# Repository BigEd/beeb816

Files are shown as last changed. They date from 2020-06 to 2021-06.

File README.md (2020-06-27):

# beeb816
65816 upgrade for BBC Micro, including lots of fast RAM

rtl           -       original level1b RTL
emu6502_rtl   -       stripped back 6502 emulation only, trialling clock delays for CPU vs BBC
trial_rtl     -       extension of above to allow access to high memory in 816 mode only
trial2_rtl    -       extension of above to allow ROM/RAM remapping, but no clock switching
trial3_rtl    -       full functionality with synchronous CPU clock/async BBC clock switch
trial4_rtl    -       full functionality with async CPU and BBC clock switches
trial5_rtl    -       full functionality with async CPU and BBC clock switches, force all mapping/selection to occur in PHI1/switch in PHI1
trial6_rtl    -       full functionality with synchronous CPU clock/async BBC clock switch, force all mapping/selection to occur in PHI1/switch in PHI1

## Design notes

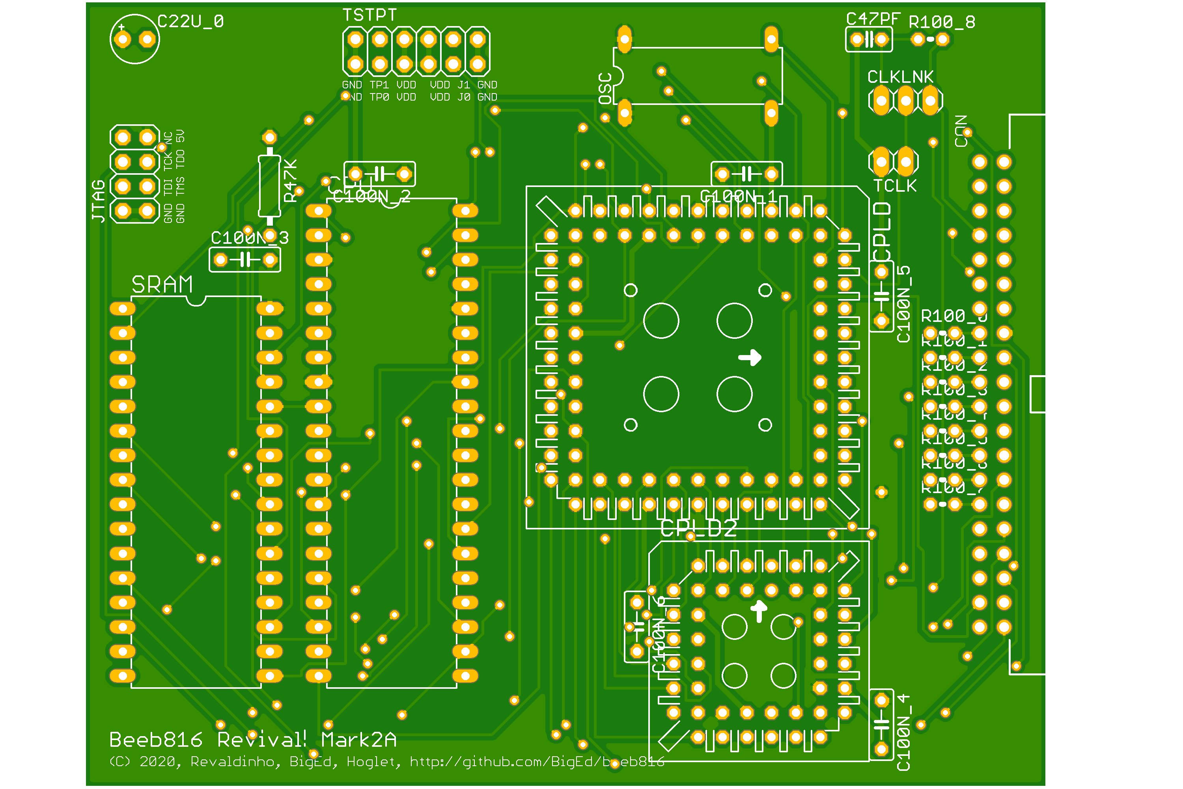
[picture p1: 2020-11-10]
doc/l1b_mk2a_top.png

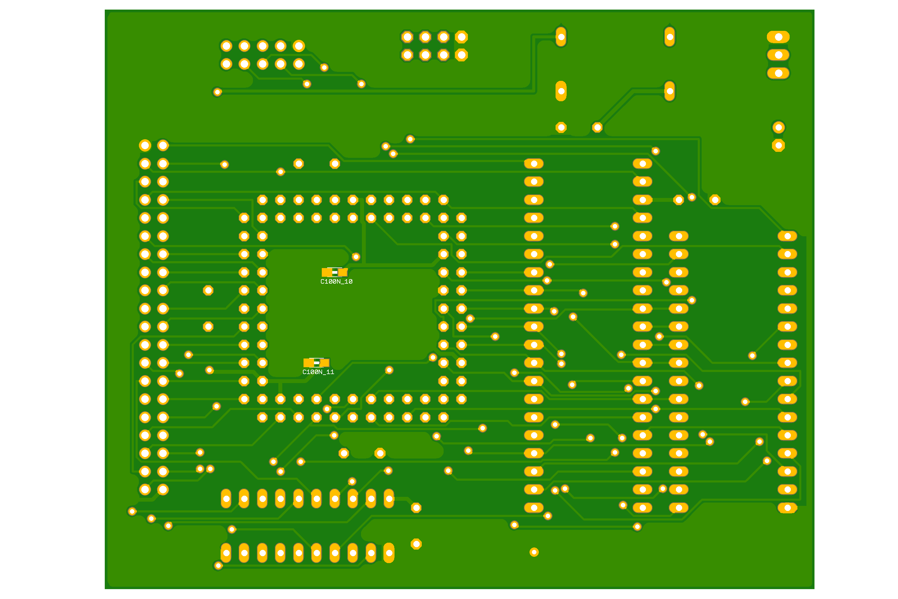
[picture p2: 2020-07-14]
pcb/releases/rc-1/l1b_mk2_bot.png

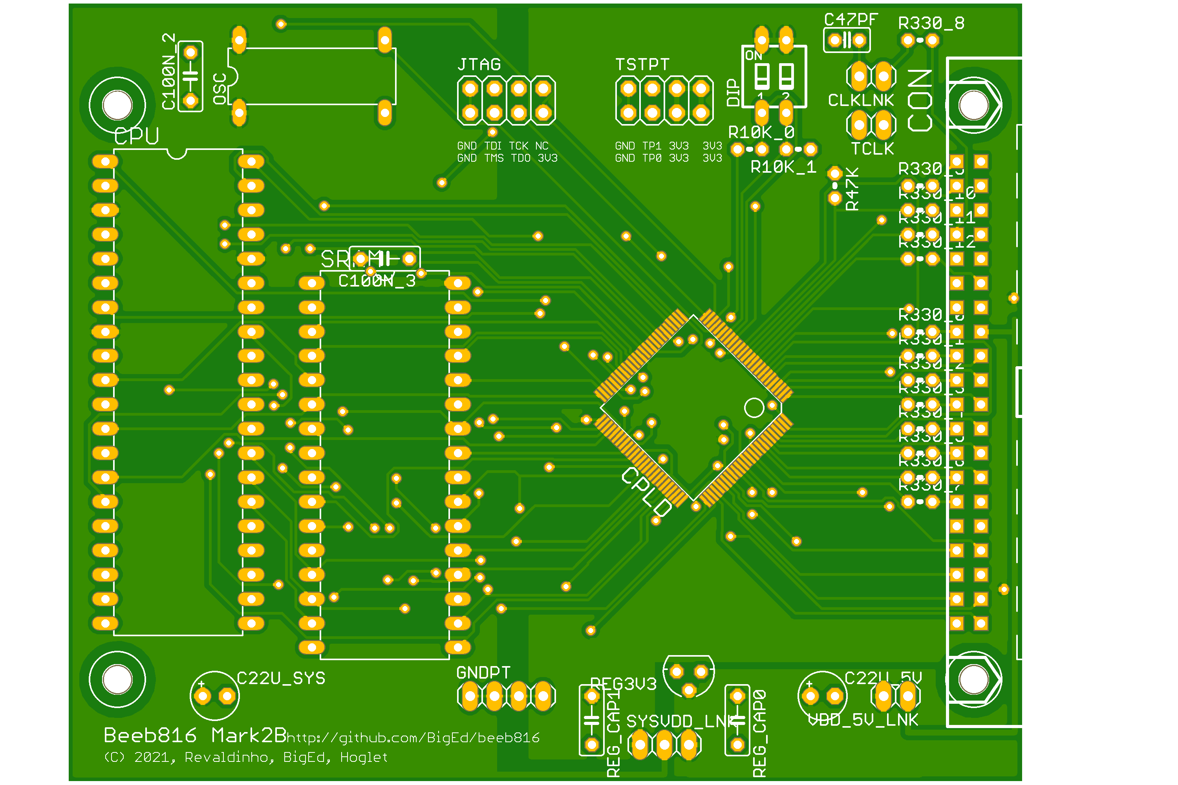
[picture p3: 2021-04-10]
pcb/releases/rc-3/beeb816_mk2b_top.png

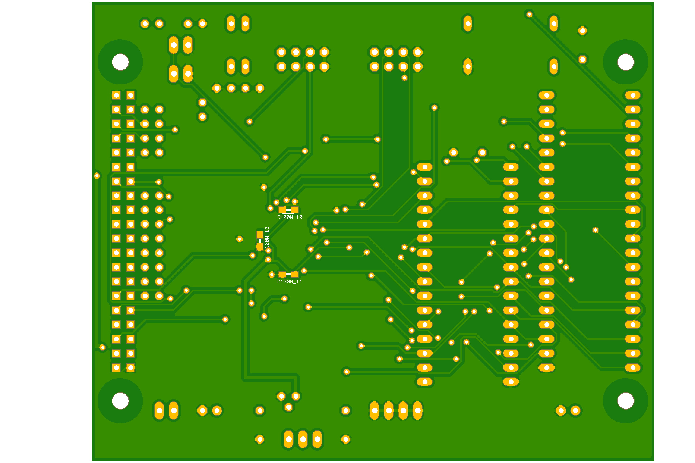
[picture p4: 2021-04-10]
pcb/releases/rc-3/beeb816_mk2b_bot.png

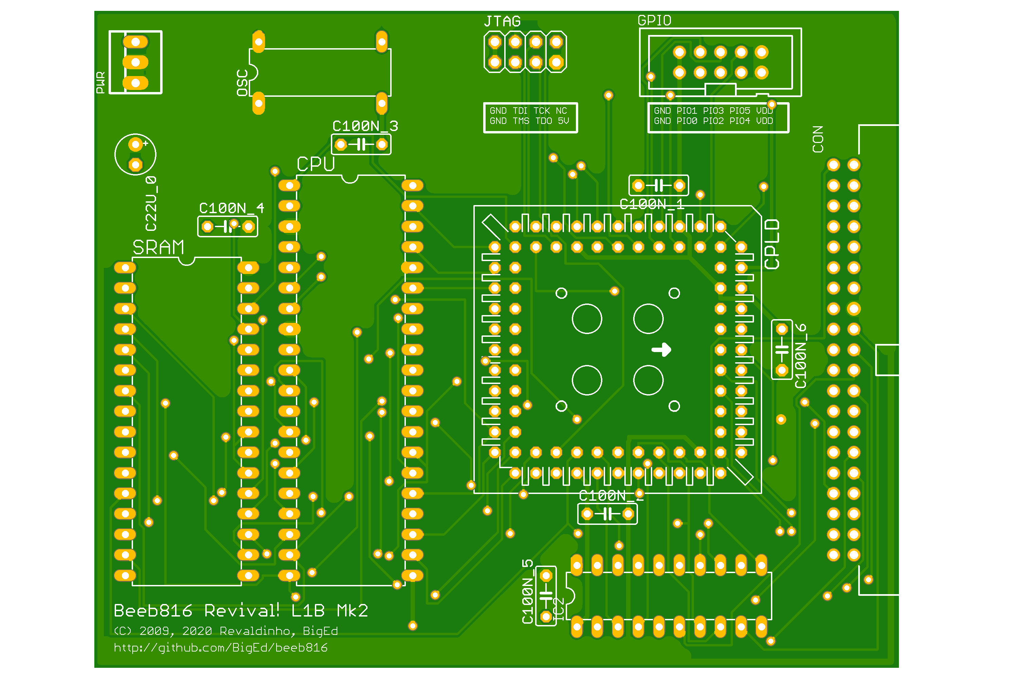
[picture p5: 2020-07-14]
pcb/releases/rc-1/l1b_mk2_top.png

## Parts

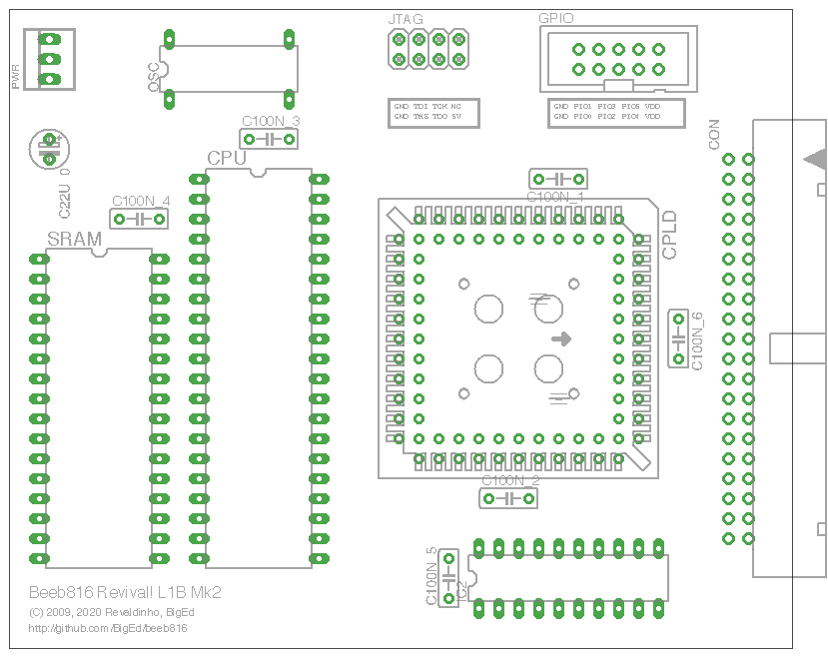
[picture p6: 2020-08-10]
doc/Beeb816_mk2_Components.png

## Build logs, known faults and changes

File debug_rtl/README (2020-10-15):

#!/bin/bash
# ./README [xc9572|xc95108] [$defines]
design=level1b_mk2_m

if [ $# -lt 1 ]; then
    target=xc95108-15-pc84
else
    target=$1
fi

if [ $# -lt 2 ]; then
    defines=""
else
    defines=$2
fi

echo "Building for $target"

BUILD_SCR=../scripts/build.py

${BUILD_SCR}  \
    -a "xst: -define { $defines }"  \
    -m ${design} \
    -d build_${target}_p3_ff \
    -f -t ${target}  \
    -c ${design}.ucf -o speed
# mv build_${target}_p3_ff/${design}.jed ./${design}_${defines}.jed
#    -a "cpldfit: -pterms 12" \

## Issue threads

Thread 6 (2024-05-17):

Wish I had this in 1988..

janrinze, 2024-05-17:
In 1988 my Atom got a 8Mhz 65SC816 (GE Plessey?)
Your PCB would have been an awesome upgrade.
My Roland Atom works fine, I don't think it has support for the 65816.
Always was a little envious of the Apple II GS with lots of RAM. ;-)

Are there boards and CPLDs available?
The 40 pin connector to 40 pin DIL is a 'special' too. I'm not sure where I left mine or how to get one these days.

And.. how about software?

BigEd, 2024-06-23:
Hi Jan... software... yes, I think Dominic Beesley's 65816 port of BBC Basic does some of what we'd hope for.  Perhaps that's everything we have at present.

I hope you've seen these forum threads - might be a good place to ask questions (I missed this one!)
[A bit of progress on our Beeb816 project](https://retrocomputingforum.com/t/a-bit-of-progress-on-our-beeb816-project/1431) at retrocomputing forum
[Beeb816 - an in-socket upgrade for Acorn's 8 bit machines](http://forum.6502.org/viewtopic.php?f=4&t=6713) at 6502.org

CPLD availability is a bit of a problem these days - let's discuss that.

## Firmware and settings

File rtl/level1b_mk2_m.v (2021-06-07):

`timescale 1ns / 1ns
//
// Mark2A/B - main CPLD code
//
// Define this to build firmware for the Mark2B board which merges the dual CPLDs from
// the Mark2A into a single device
// `define MARK2B 1
//
// Depth of pipeline to delay switches to HS clock after an IO access.
// Modified now to count SYNCs rather than cycles
`define IO_ACCESS_DELAY_SZ     4

// Define this to force-keep some clock nets to reduce design size
`define FORCE_KEEP_CLOCK 1

// Define to drive clocks to test points tp[1:0]
//`define OBSERVE_CLOCKS 1

// Set one of these to falling edge of RAMOEB by one buffer when running with fast SRAM
//`define DELAY_RAMOEB_BY_1
`define DELAY_RAMOEB_BY_2
//`define DELAY_RAMOEB_BY_3

// Fixed clock divider now - default is /4 but can still compile with /2
`define CLKDIV4NOT2 1

// Define this for BBC MASTER support
// `define ALLOW_BBC_MASTER_HOST 1

// Decoding for fixed address areas of RAM
`define LOWMEM_1K              (!cpu_data[7] & !cpu_adr[15]  & !(|cpu_adr[14:10]))
`define LOWMEM_12K             (!cpu_data[7] & !cpu_adr[15] & !(cpu_adr[14] | (cpu_adr[13]&cpu_adr[12])))
`define LYNNE_20K              (!cpu_data[7] & !cpu_adr[15] & (cpu_adr[14] | (cpu_adr[13]&cpu_adr[12])))

// Define this to bring decoding back into the main CPLD (mainly for capacity evaluation). Note
// that the address lsb latches are still assumed external to keep the same pin out. Must be defined
// for the Mark2B board.
// `define LOCAL_DECODING 1

`ifdef MARK2B
  `define ALLOW_BBC_MASTER_HOST 1
  `define ALLOW_BEEB_HOST 1
  `define ALLOW_ELK_HOST 1
  // All-in-one CPLD - no offloading of decoding to external IC
  `define LOCAL_DECODING 1
  // Remove this definition to improve MHz at cost of logic
  `undef FORCE_KEEP_CLOCK
  // Enough macrocells to export the clock to test points
  `define OBSERVE_CLOCKS 1
`else
  `define ALLOW_BEEB_HOST 1
  `define ALLOW_ELK_HOST 1
`endif //  `ifdef MARK2B

`ifdef LOCAL_DECODING
  `define ELK_PAGED_ROM_SEL 16'hFE05
  `define PAGED_ROM_SEL 16'hFE30
  `define BPLUS_SHADOW_RAM_SEL 16'hFE34
  `define DECODED_SHADOW_REG  (((`L1_BPLUS_MODE) || (`L1_MASTER_MODE)) ? (cpu_adr==`BPLUS_SHADOW_RAM_SEL) : 1'b0 )
  `define DECODED_ROM_REG     ((`L1_ELK_MODE)? (cpu_adr==`ELK_PAGED_ROM_SEL) : (cpu_adr==`PAGED_ROM_SEL))
  // Flag FE4x (VIA) accesses and also all &FC, &FD expansion pages
  `define DECODED_FE4X        ((cpu_adr[15:4]==12'hFE4) || (cpu_adr[15:9]==7'b1111_110))
`else // !`ifdef LOCAL_DECODING
  `define DECODED_SHADOW_REG dec_shadow_reg
  `define DECODED_ROM_REG    dec_rom_reg
  `define DECODED_FE4X       dec_fe4x
`endif // !`ifdef LOCAL_DECODING

`define MAP_CC_DATA_SZ                8
`define SHADOW_MEM_IDX                7
`define HOST_TYPE_1_IDX               6
`define HOST_TYPE_0_IDX               5
`define MAP_ROM_IDX                   4
`define MAP_HSCLK_EN_IDX              2

`define BBC_PAGEREG_SZ                4    // only the bottom four ROM selection bits
`define CPLD_REG_SEL_SZ               3
`define CPLD_REG_SEL_BBC_SHADOW_IDX   2
`define CPLD_REG_SEL_MAP_CC_IDX       1
`define CPLD_REG_SEL_BBC_PAGEREG_IDX  0

`ifndef CLKDIV4NOT2
  `define CLKDIV4NOT2 1
`endif

`ifdef ALLOW_ELK_HOST
  `define L1_ELK_MODE    (map_data_q[`HOST_TYPE_1_IDX:`HOST_TYPE_0_IDX]==2'b10)
`else
  `define L1_ELK_MODE    1'b0
`endif

`ifdef ALLOW_BEEB_HOST
  `define L1_BEEB_MODE   (map_data_q[`HOST_TYPE_1_IDX:`HOST_TYPE_0_IDX]==2'b00)
  `define L1_BPLUS_MODE  (map_data_q[`HOST_TYPE_1_IDX:`HOST_TYPE_0_IDX]==2'b01)
`else
  `define L1_BEEB_MODE   1'b0
  `define L1_BPLUS_MODE  1'b0
`endif

`ifdef ALLOW_ELK_HOST
  `define ALLOW_BEEB_OR_ELK_HOST 1
`elsif ALLOW_BEEB_HOST
  `define ALLOW_BEEB_OR_ELK_HOST 1
`endif

`ifdef ALLOW_BBC_MASTER_HOST
  `ifdef ALLOW_BEEB_OR_ELK_HOST
    `define L1_MASTER_MODE (map_data_q[`HOST_TYPE_1_IDX:`HOST_TYPE_0_IDX]==2'b11)
  `else
    `define L1_MASTER_MODE (1'b1)
  `endif
`else
  `define L1_MASTER_MODE (1'b0)
`endif

module level1b_mk2_m (
                      input [15:0]   cpu_adr,
                      input          resetb,
                      input          cpu_vpb,
                      input          cpu_e,
                      input          cpu_vda,
                      input          cpu_vpa,
                      input          bbc_phi0,
                      input          hsclk,
                      input          cpu_rnw,
                      input [1:0]    j,
                      output [1:0]   tp,
`ifdef MARK2B
                      input          rdy,
                      input          nmib,
                      input          irqb,
                      output         cpu_rstb,
                      output         cpu_rdy,
                      output         cpu_nmib,
                      output         cpu_irqb,
                      output [15:0]  bbc_adr,
`else
                      input          dec_shadow_reg,
                      input          dec_rom_reg,
                      input          dec_fe4x,
                      inout          rdy,
                      inout          nmib,
                      inout          irqb,
                      output         lat_en,
                      output [15:12] bbc_adr,
`endif
                      inout [7:0]    cpu_data,
                      inout [7:0]    bbc_data,
                      output         ram_web,
                      output         ram_ceb,
                      output         ram_oeb,
                      output [18:14] ram_adr,
                      output         bbc_sync,
                      output         bbc_rnw,
                      output         bbc_phi1,
                      output         bbc_phi2,
                      output         cpu_phi2
                  );
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

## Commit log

2016-06-02 initial import from SVN HEAD as of 2013-10-17
    [l1b_rev1.brd]
2016-06-26 removed unused optional code from switch
2020-06-16 Add new clock switch testbenches
2020-06-22 First signs of life with new clock switch/sync clocks
2020-06-23 Working but not thoroughly tested version with clock switch - running well at 4MHz (divided from VDU clock 16MHz)
2020-06-23 Working Trial3_rtl ready to try new (old) async clock switch)
2020-06-23 Trial4 - working simulation with original async clock switch
2020-07-04 Add alternative stop-on-phi1 clock switch + build/simulation options
2020-07-05 Make a couple of ifdef options standard - longer clock switch delay LS->HS and always use the dummy access latch
2020-07-11 Add new rtl2/ dir with CPLD code development for MK2 board
2020-07-11 add initial code for mk2 version of PCB
2020-07-12 PCB: updated DRU deck (more via spacing, less spacing from copper to board edge) + potential release candidate layout
2020-07-12 PCB: more minor pin moves
2020-07-14 PCB: More pin optimisations, netlist correction
    [l1b_rev1.brd]
2020-07-14 Update testbench for new PCB/CPLD version with address latch
2020-07-14 Pin changes, more prerouting for new PCB
2020-07-14 Add PCB release data
    [l1b_mk2.brd]
2020-08-09 White space changes only, but snapshot of first working Mk2 board status in hardware
2020-08-10 Add board layout for Wiki
2020-08-16 Add an extra cycle to the IO area delay to fix sound above 16MHz
    [level1b_mk2_m.v]
2020-08-17 Remove some of the dead time in clock switches to the low clock
2020-08-17 Add 1 cycle delay to IO switch for >16MHz; add some experimental code to latch HIMEM/HISYNC but keep it disabled for now
2020-08-19 Add config bit to switch between paged and VRAM caching
2020-08-20 Update for PCB Hack#1 - separation of OEB and CEB + refined check for IO area when slowing down switch back to HS clock. Check for only FCxx-FEDF, allowing faster tube accesses
2020-08-23 Use slow clock to delay HS switch instead of HS pipeline
2020-08-23 Add ram_adr14/15 control via GPIO bits (and PCB hack)
2020-08-25 tidy up clock switch with comment and defines for -15ns parts
2020-08-27 Slight simplification to switch - remove 'selected' FFs which are redundant, removal of reset in LS pipe
2020-09-15 Remove MAP_RAM bit, speed up HIMEM and DUMMY_ACCESS computation, bug fix in MOS_VDU_SYNC
    [level1b_mk2_m.v]
2020-09-19 Reinstate delay for -7C part, fix divider
    [level1b_mk2_m.v]
2020-09-20 Archive and remove old mk1 board firmware, rename mk2 rtl dir
2020-09-21 Replace verilog files missing after moving directories
    [level1b_mk2_m.v]
2020-09-23 Add delay into clock switch if DIV4 not implemented
2020-10-10 Bug fix: Shadow mode can be invoked without need for Turbo. Enabled Master Shadow Mode control aliassing
    [level1b_mk2_m.v]
2020-10-15 Enforce BBC PHI2 later than PHI1 in delay chain
2020-10-15 Make default pin slew SLOW
2020-10-23 Add fix for /4 in clock switch to handle HSCLK ~= LSCLK
2020-10-24 Change IO switch delay from pipeline to counter
2020-10-24 Bug fix - IO max delay time should be DELAY-2 rather than DELAY-1 to allow for additional pipe stage and size of counter
    [level1b_mk2_m.v]
2020-10-24 restore older ripple counter version of clk switch
2020-10-24 Back out previous commit on IO delay ctr - has caused an issue with not switching
    [level1b_mk2_m.v]
2020-10-28 Reduce polygon width to create power fenestrations
2020-11-01 Define pin position for GPIOS[5:3] as probe points, use force keep on switched clock net
2020-11-10 Docs - add snapshot of mk2a board
2020-12-01 Update memory map for MK2 board to match MK2A. Some trouble fitting in the CPLD, so have temporarily reduced the IO delay pipe to 4 FFs and removed the ROM write protection logic
2021-01-12 Update PCB control files from option2_pcb branch
2021-01-12 Bring over Mark2A board files
2021-01-13 Restore old code to use one retimer on the slow clock domain to speed up switching
2021-01-17 Unify master/elk/bbc code for mk2b board ; predefine combination of ifdefs for the mk2b
2021-03-06 Bring some pin headers into board to line up with smaller buffer board
2021-03-06 Update README to use Make for PCBs
2021-03-11 Add Beeb816 Mk2B pin out into UCF file for trial synthesis and fitting
2021-04-10 Commit all files from Beeb816_mk2b board run
2021-04-10 Add all files for the Beeb816 Mk2B board
    [beeb816_mk2b.brd]
2021-04-25 Beeb816_mk2b update: Temporary fix for Richs board (drive IRQ on TP1); reinstate async divider option ; undef force_keep clock node for Beeb816 build only
    [level1b_mk2_m.v]
2021-04-30 Add delay to CPU clk vs host, slightly elongate PHI1 for clock switch
2021-04-30 Delay CPU clock more wrt host to fix 1MHz bus/Datacentre hold times
    [level1b_mk2_m.v]
2021-05-03 Make clkdel length a define ; reinstate FORCE_KEEP on clock net by default for MK2A board
2021-05-04 Remove FFs from clock switch - with lsclk and cpuclk now synchronous, no need for retiming chain
2021-05-08 Fix VRAM size at 31K, remove VRAM_SZ bit (return 0 on read); Fix jumper usage for divider settings on startup
    [level1b_mk2_m.v]
2021-05-09 Use DIP2 to select 2 or 3 delay chain elements, retire div6 setting
2021-05-10 No functional change - refactor clkctrl_phi2.v to make it easy to plug in experimental divide-by-2-3-4 unit (by default the current divide by 2-4 is included)
2021-05-14 Fixes to shadow mode on Master
    [level1b_mk2_m.v]
2021-05-14 Invert state of static SYNC signal when in high speed mode
    [level1b_mk2_m.v]
2021-05-18 Correct typo in ROM bank allocation
    [level1b_mk2_m.v]
2021-05-21 Reinstate programmable VRAM 20K (bit 3 set) or 31K (bit 3 reset - default on startup)
    [level1b_mk2_m.v]
2021-05-21 Fix clock divider at /4. Delay line delay set at 3 FFs. Master host bypasses delay line automatically
    [level1b_mk2_m.v]
2021-05-22 Fix a bug in the VRAM size setting reg bit
    [level1b_mk2_m.v]
2021-05-22 Fix SHADOW mode for Beeb/Elk ; add slow div8 define options for debug to clkctrl module
    [level1b_mk2_m.v]
2021-05-22 Add ALLOW_BBC_MASTER_HOST define (to cover all master options), simplify a couple of remapping equations
2021-05-26 Rewrite RAM remapping to allow Master to use all of main bank for VRAM but map LYNNE only in shadow mode; DIP2 is Master Mode on board
2021-05-31 Fix recent refactor error in mos_vdu_sync_q
    [level1b_mk2_m.v]
2021-05-31 Increase IO_ACCESS_DELAY_SZ from 3 to 4 (audio issues with Tube Elite)
    [level1b_mk2_m.v]
